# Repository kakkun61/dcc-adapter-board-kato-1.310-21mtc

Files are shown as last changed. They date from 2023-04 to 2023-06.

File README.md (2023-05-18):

# DCC 21MTC Adapter Board for Kato 1-310

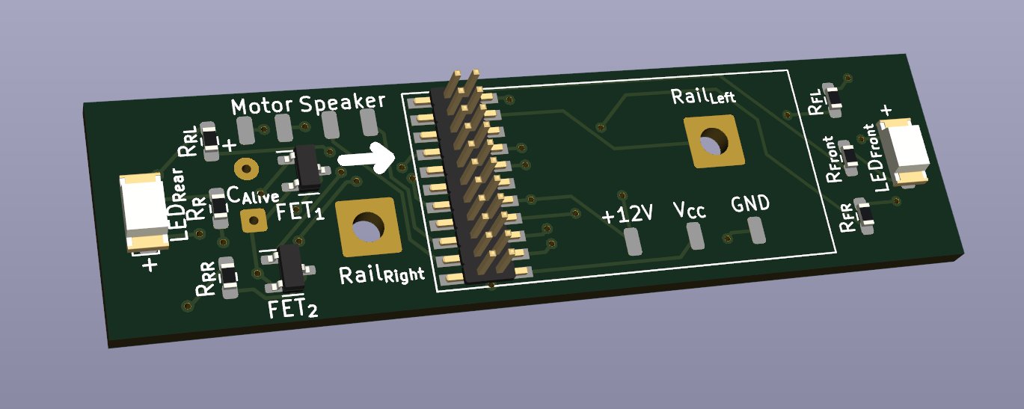
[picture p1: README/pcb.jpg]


## Parts

Expected parts are:

- Side-emit LED — Bulb color
  - Quantity 2
  - https://www.led-paradise.com/phone/product/1890
- Side-emit LED — Red color
  - Quantity 4
  - https://www.led-paradise.com/phone/product/1887
- MOSFET IC ― N channel
 	- Quantity 2
 	- https://eleshop.jp/shop/g/gAA5417/
- 1/20 inch-pitch SMD pin header
  - Quantity 11
  - https://akizukidenshi.com/catalog/g/gC-10704/
- 表面実装抵抗
  - Quantity 6
  - 16×08 mm
  - 500-1k Ω

## Order to Elecrow

Rename and archive gerber files:

```
make
```

_dcc-adapter-board-kato-1.310-21mtc_elecrow.zip_ will be made and this is a file to submit to Elecrow.

Order parameters are:

Parameter | Argument
---|---
Layer | 2
Dimensions | 60×16 mm
Thickness | 1.0 mm
Color | Black
Surface Finish | HASL
Castellated Hole | No
Copper Weight | 1 oz

## License

[CC BY 4.0](https://creativecommons.org/licenses/by/4.0/deed) 岡本和樹

[Open Source Hardware](https://www.oshwa.org/)

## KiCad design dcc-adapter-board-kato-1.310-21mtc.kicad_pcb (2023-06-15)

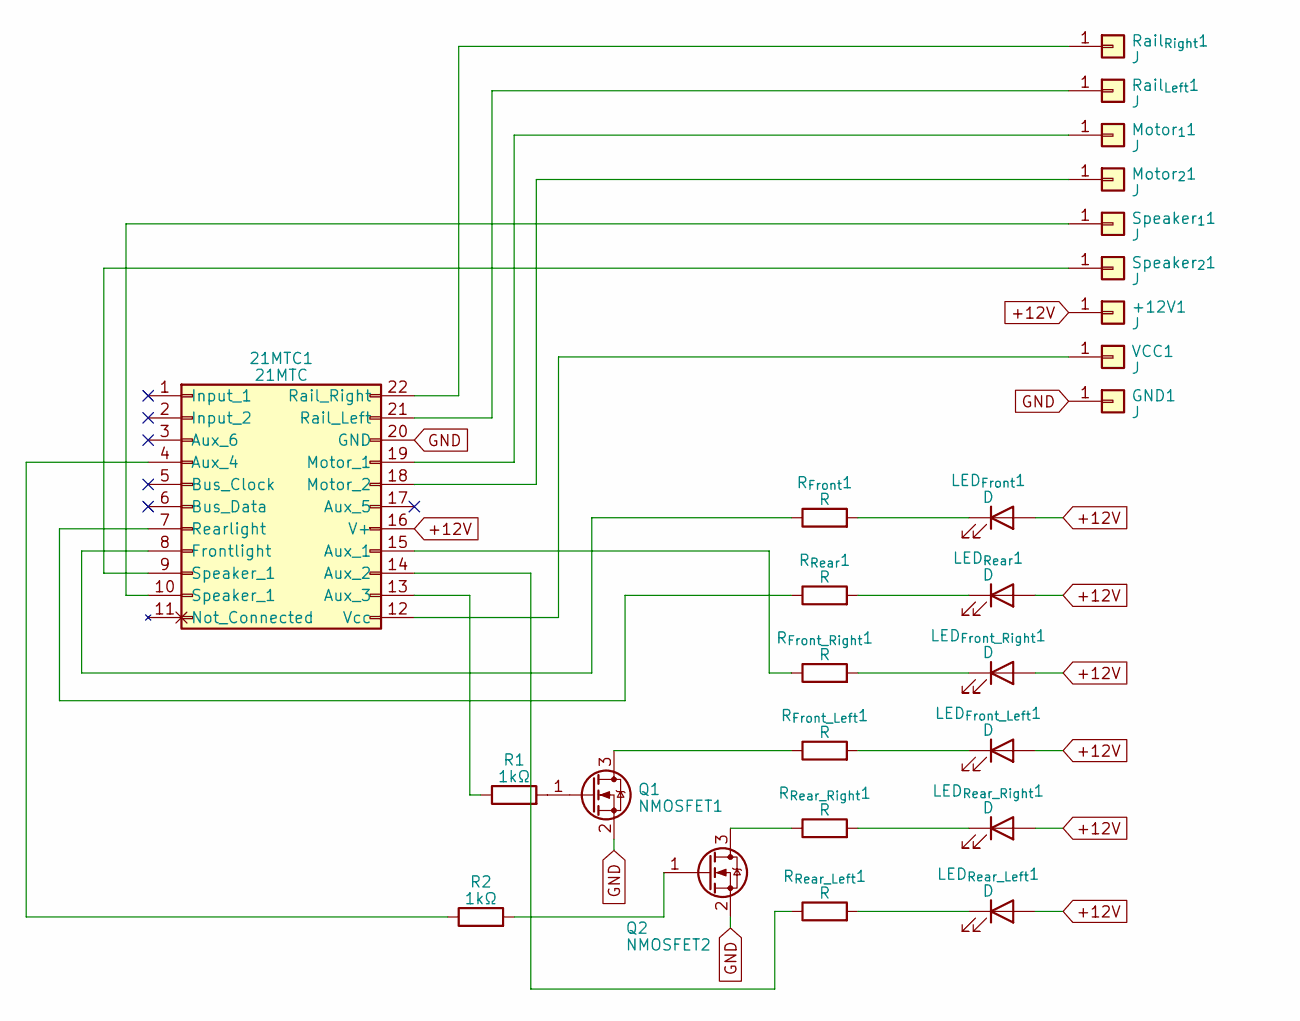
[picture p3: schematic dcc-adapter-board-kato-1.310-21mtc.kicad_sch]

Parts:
21MTC1: 21MTC
+12V1: J; SolderWirePad_1x01_SMD_1x2mm
GND1: J; SolderWirePad_1x01_SMD_1x2mm
LED_{Front_Left}1: D; LED_Side_Emitting_335
LED_{Front_Right}1: D; LED_Side_Emitting_335
LED_{Front}1: D; LED_Side_Emitting_335
LED_{Rear_Left}1: D; LED_Side_Emitting_335
LED_{Rear_Right}1: D; LED_Side_Emitting_335
LED_{Rear}1: D; LED_Side_Emitting_335
Motor_{1}1, Motor_{2}1: J; SolderWirePad_1x01_SMD_1x2mm
Q1: NMOSFET1; SOT-23
Q2: NMOSFET2; SOT-23
R1, R2: 1kΩ; R_0603_1608Metric_Pad0.98x0.95mm_HandSolder
R_{Front_Left}1: R; R_0603_1608Metric_Pad0.98x0.95mm_HandSolder
R_{Front_Right}1: R; R_0603_1608Metric_Pad0.98x0.95mm_HandSolder
R_{Front}1: R; R_0603_1608Metric_Pad0.98x0.95mm_HandSolder
R_{Rear_Left}1: R; R_0603_1608Metric_Pad0.98x0.95mm_HandSolder
R_{Rear_Right}1: R; R_0603_1608Metric_Pad0.98x0.95mm_HandSolder
R_{Rear}1: R; R_0603_1608Metric_Pad0.98x0.95mm_HandSolder
Rail_{Left}1: J; SolderWire-1.5sqmm_1x01_D1.7mm_OD3.9mm
Rail_{Right}1: J; SolderWire-1.5sqmm_1x01_D1.7mm_OD3.9mm
Speaker_{1}1, Speaker_{2}1: J; SolderWirePad_1x01_SMD_1x2mm
VCC1: J; SolderWirePad_1x01_SMD_1x2mm

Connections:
+12V: 21MTC1.16 (V+), +12V1.1, LED_{Front_Left}1.2 (A), LED_{Front_Right}1.2 (A), LED_{Front}1.2 (A), LED_{Rear_Left}1.2 (A), LED_{Rear_Right}1.2 (A), LED_{Rear}1.2 (A)
GND: 21MTC1.20 (GND), GND1.1, Q1.2 (S), Q2.2 (S)
unnamed: 21MTC1.15 (Aux_1), R_{Front_Right}1.1
unnamed: 21MTC1.14 (Aux_2), R_{Rear_Left}1.1
unnamed: 21MTC1.13 (Aux_3), R1.1
unnamed: 21MTC1.4 (Aux_4), R2.1
unnamed: 21MTC1.8 (Frontlight), R_{Front}1.1
unnamed: 21MTC1.19 (Motor_1), Motor_{1}1.1
unnamed: 21MTC1.18 (Motor_2), Motor_{2}1.1
unnamed: 21MTC1.21 (Rail_Left), Rail_{Left}1.1
unnamed: 21MTC1.22 (Rail_Right), Rail_{Right}1.1
unnamed: 21MTC1.7 (Rearlight), R_{Rear}1.1
unnamed: 21MTC1.12 (Vcc), VCC1.1
unnamed: LED_{Front_Left}1.1 (K), R_{Front_Left}1.2
unnamed: LED_{Front_Right}1.1 (K), R_{Front_Right}1.2
unnamed: LED_{Front}1.1 (K), R_{Front}1.2
unnamed: LED_{Rear_Left}1.1 (K), R_{Rear_Left}1.2
unnamed: LED_{Rear_Right}1.1 (K), R_{Rear_Right}1.2
unnamed: LED_{Rear}1.1 (K), R_{Rear}1.2
unnamed: Q1.3 (D), R_{Front_Left}1.1
unnamed: Q1.1 (G), R1.2
unnamed: Q2.3 (D), R_{Rear_Right}1.1
unnamed: Q2.1 (G), R2.2
unnamed: 21MTC1.10 (Speaker_1), Speaker_{1}1.1
unnamed: 21MTC1.9 (Speaker_1), Speaker_{2}1.1

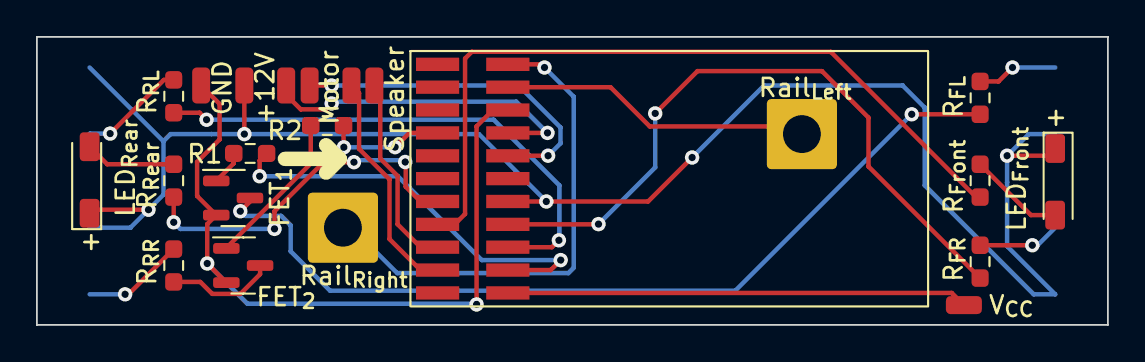
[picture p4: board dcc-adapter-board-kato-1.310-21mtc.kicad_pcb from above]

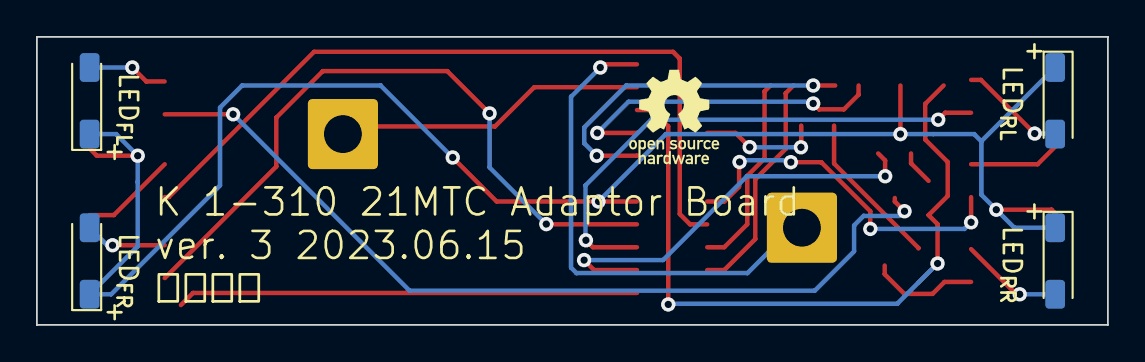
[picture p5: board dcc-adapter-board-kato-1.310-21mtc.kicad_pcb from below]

Board: 2 copper layers, 59.5 x 16.0 mm, 27 parts (5 on the bottom side), 25 nets.

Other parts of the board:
G1: LOGO

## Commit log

2023-04-28 KiCad の出力するファイル名が …-F_SilkS.ghr から …-F_Silkscreen.gbr に変わったんか
2023-04-28 試作1号 フィードバック
    ねじ穴位置修正
    プラス表記
    銅層の文字をシルクスクリーンに移動
    [dcc-adapter-board-kato-1.310-21mtc.kicad_pcb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]
2023-05-17 改修
    • 21MTC のピン配置がまちがっていた
    • アライブキャパシター用端子をなくした
    • +12V・GND パッドを使うようにする
    [dcc-adapter-board-kato-1.310-21mtc.kicad_pcb, dcc-adapter-board-kato-1.310-21mtc.kicad_sch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]
2023-05-17 update gerbers
    [dcc-adapter-board-kato-1.310-21mtc-B_Adhesive.gbr, dcc-adapter-board-kato-1.310-21mtc-B_Courtyard.gbr, dcc-adapter-board-kato-1.310-21mtc-B_Cu.gbr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]
2023-05-28 v2 フィードバック
    • MOSFET のゲートの前段に抵抗を追加
    • ねじ穴の位置を 0.5mm 外側に移動
    [dcc-adapter-board-kato-1.310-21mtc.kicad_pcb, dcc-adapter-board-kato-1.310-21mtc.kicad_sch]
2023-06-13 シルクスクリーン配置変更
    [dcc-adapter-board-kato-1.310-21mtc.kicad_pcb]
2023-06-13 create-gerber.py とそれで生成されたファイル
    時刻以外の差分はよく分からん
    [dcc-adapter-board-kato-1.310-21mtc-B_Adhesive.gbr, dcc-adapter-board-kato-1.310-21mtc-B_Courtyard.gbr, dcc-adapter-board-kato-1.310-21mtc-B_Cu.gbr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]
2023-06-13 gerber ファイルは管理下外に
    [dcc-adapter-board-kato-1.310-21mtc-B_Adhesive.gbr, dcc-adapter-board-kato-1.310-21mtc-B_Courtyard.gbr, dcc-adapter-board-kato-1.310-21mtc-B_Cu.gbr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]
2023-06-13 make から呼びだせるように
